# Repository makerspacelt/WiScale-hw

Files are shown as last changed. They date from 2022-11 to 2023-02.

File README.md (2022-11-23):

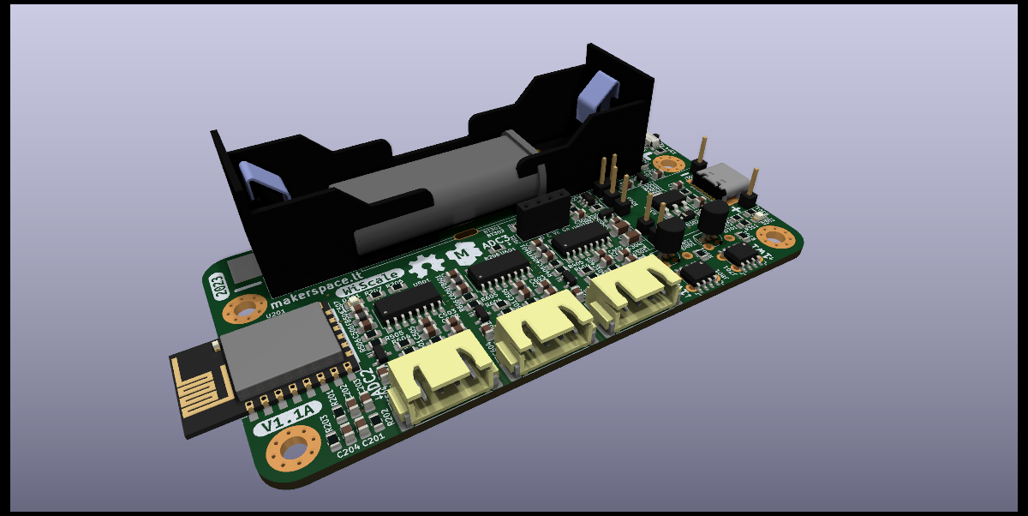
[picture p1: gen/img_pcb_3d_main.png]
PCB 3d main


This is ESP8266 (ESP-12F) and HX711 based weight monitoring device.

* Designed to be pretty small.
* Supports multiple load cells.
* Can be populated with 18650 battery
* Can be operated in ultra low power mode

Dev NOTE: before commit, run `./kibot.sh` to regenerate documentation, bom, gerbers and other assets.

* [schematics.pdf](gen/schematics.pdf)
* [pcb.pdf with dimensions](gen/pcb.pdf)
* [ibom.html](gen/bom_ibom.html)
* [gerbers.zip](gen/gerbers/gerbers.zip)

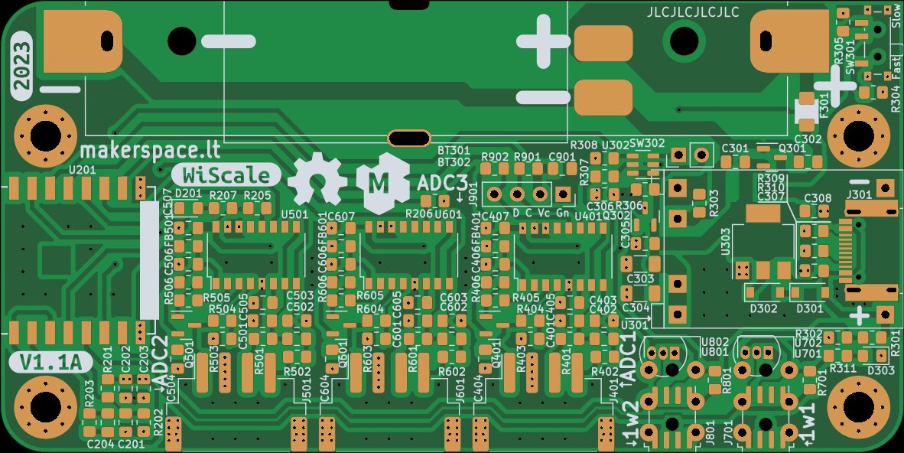
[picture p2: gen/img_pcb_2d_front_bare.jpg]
PCB 2d front bare

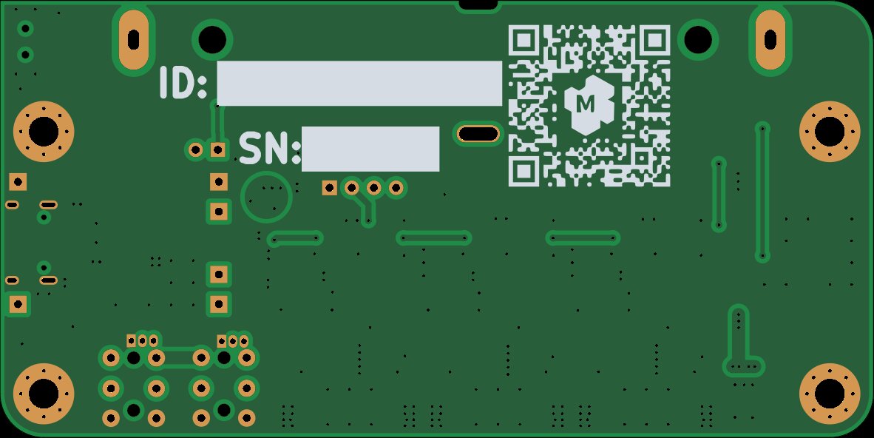
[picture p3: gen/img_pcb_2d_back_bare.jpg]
PCB 2d back bare


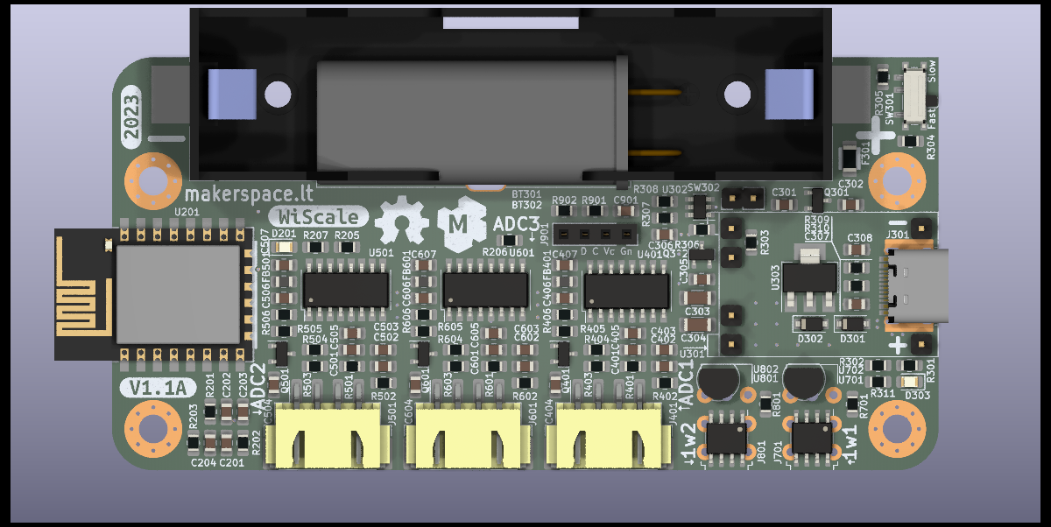
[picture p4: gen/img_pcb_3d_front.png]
PCB 3d front


## Normal operation

The circuit should be powered either via a USB connector on the LiPo charger
or battery.

## Assembly and hardware configuration notes

### LiPo charger

Chargers(U301) with protection can be used.

For use without onboard charger R303 must be shorted and U301,R301 and R302
can be omitted. 

### Low-power sleep

A timer is equipped with selectable(SW301) wake-up settings(R304 and R305).

For applications that do not require a low-power sleep, timer can be bypassed
by shorting out R306. Following components can be omitted in assembly:

* U302
* Q302
* SW301,SW302
* R304,R305,R307,R308

### ADC configuration

To reduce noise on measurements capacitors(C401,C402,C403) on ADC input are
placed. As a side effect, they slow down reading settling time after weight
change. Removing these capacitors will give a fast reading but increase spread
by about 3 times.

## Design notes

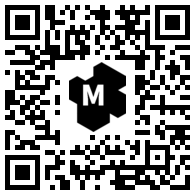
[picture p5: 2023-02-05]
gen/qr_link.png

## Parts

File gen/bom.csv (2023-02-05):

Row | Description | Part | References | Value | Footprint | Quantity Per PCB | Status | Datasheet | LCSC Part Number | MPN
1 | Single-cell battery | Battery_Cell | BT301 | 18650 | BAT_BH-18650-PC | 1 |  | https://datasheet.lcsc.com/lcsc/2204021730_MYOUNG-BH-18650-B1BA002_C2988620.pdf | C2988620 | BH-18650-B1BA002
2 | Single-cell battery | Battery_Cell | BT302 | 801437 | BAT_IP801437D3R2 | 1 |  | ~
3 | Unpolarized capacitor | C | C201,C202,C204,C305,C306,C401,C403,C405,C501,C503,C505,C601,C603,C605,C901 | 100n | C_0805_2012Metric_Pad1.18x1.45mm_HandSolder | 15 |  | ~
4 | Unpolarized capacitor | C | C402,C406,C502,C506,C602,C606 | 1u | C_0805_2012Metric_Pad1.18x1.45mm_HandSolder | 6 |  | ~
5 | Unpolarized capacitor | C | C203,C301,C302,C307,C308,C404,C407,C504,C507,C604,C607 | 10u | C_0805_2012Metric_Pad1.18x1.45mm_HandSolder | 11 |  | ~
6 | Unpolarized capacitor | C | C303,C304 | 100u | C_1206_3216Metric_Pad1.33x1.80mm_HandSolder | 2 |  | https://datasheet.lcsc.com/lcsc/1811061115_Murata-Electronics-GRM31CR61A107ME05L_C312983.pdf | C312983 | GRM31CR61A107ME05L
7 |  | 1N4148W | D301,D302 | 1N4148WL | D_SOD-123 | 2 |  | https://www.vishay.com/docs/85748/1n4148w.pdf | C2908120
8 | Light emitting diode | LED | D201 | BLUE | LED_0805_2012Metric_Pad1.15x1.40mm_HandSolder | 1 |  | https://datasheet.lcsc.com/lcsc/2211030000_XINGLIGHT-XL-2012UBC_C965817.pdf | C965817 | XL-2012UBC
9 | Light emitting diode | LED | D303 | GREEN | LED_0805_2012Metric_Pad1.15x1.40mm_HandSolder | 1 |  | https://datasheet.lcsc.com/lcsc/2211030000_XINGLIGHT-XL-2012UBC_C965817.pdf | C965817 | XL-2012UBC
10 | Resettable fuse, polymeric positive temperature coefficient | Polyfuse | F301 | PTC 1A | Fuse_1206_3216Metric_Pad1.42x1.75mm_HandSolder | 1 |  | https://datasheet.lcsc.com/lcsc/2105241640_Jinrui-Electronic-Materials-Co--JK-nSMD100-16V_C2830246.pdf | C2830246 | JK-nSMD100/16V
11 | Ferrite bead | FerriteBead | FB401,FB501,FB601 | bead | L_0805_2012Metric_Pad1.15x1.40mm_HandSolder | 3 |  | ~
12 | Audio Jack, 3 Poles (Stereo / TRS) | AudioJack3 | J701,J801 | DS18B20 | Jack_3.5mm_Horizontal | 2 |  | ~
13 | Generic connectable mounting pin connector, single row, 01x03, script generated (kicad-library-utils/schlib/autogen/connector/) | Conn_01x03_MountingPin | J1001,J1002,J1003,J1004 | TL | JST_XH_S3B-XH-A-1_1x03_P2.50mm_Horizontal | 4 |  | ~
14 | USB 2.0-only Type-C Receptacle connector | USB_C_Receptacle_USB2.0 | J301 | USB_POWER_IN | USB_C_Receptacle_HRO_TYPE-C-31-M-12 | 1 |  | https://datasheet.lcsc.com/lcsc/2205251630_Korean-Hroparts-Elec-TYPE-C-31-M-12_C165948.pdf | C165948
15 | Generic connectable mounting pin connector, single row, 01x04, script generated (kicad-library-utils/schlib/autogen/connector/) | Conn_01x04_MountingPin | J401,J501,J601,J1005 | cell | JST_XH_S4B-XH-SM4-TB_1x04-1MP_P2.50mm_Horizontal | 4 |  | https://datasheet.lcsc.com/lcsc/1810291321_JST-Sales-America-S4B-XH-SM4-TB-LF-SN_C161861.pdf | C2905026 | S4B-XH-SM4-TB(LF)(SN)
16 | Generic connectable mounting pin connector, single row, 01x04, script generated (kicad-library-utils/schlib/autogen/connector/) | Conn_01x04_MountingPin | J901 | i2c | PinSocket_1x04_P2.54mm_Vertical | 1 |  | ~
17 | -4.0A Id, -30V Vds, P-Channel MOSFET, SOT-23 | AO3401A | Q301,Q302,Q401,Q501,Q601 | AO3401A | SOT-23 | 5 |  | http://www.aosmd.com/pdfs/datasheet/AO3401A.pdf | C347476 | AO3401A
18 | Resistor | R | R207,R307,R401,R402,R405,R501,R502,R505,R601,R602,R605 | 100 | R_0805_2012Metric_Pad1.20x1.40mm_HandSolder | 11 |  | ~
19 | Resistor | R | R308,R309,R310,R311,R701,R801,R901,R902 | 4k7 | R_0805_2012Metric_Pad1.20x1.40mm_HandSolder | 8 |  | ~
20 | Resistor | R | R203,R205,R206 | 10k | R_0805_2012Metric_Pad1.20x1.40mm_HandSolder | 3 |  | ~
21 | Resistor | R | R304 | 15k | R_0805_2012Metric_Pad1.20x1.40mm_HandSolder | 1 |  | ~
22 | Resistor | R | R202,R301 | 47k | R_0805_2012Metric_Pad1.20x1.40mm_HandSolder | 2 |  | ~
23 | Resistor | R | R201,R302,R305,R403,R406,R503,R506,R603,R606 | 180k | R_0805_2012Metric_Pad1.20x1.40mm_HandSolder | 9 |  | ~
24 | Resistor | R | R404,R504,R604 | 200k | R_0805_2012Metric_Pad1.20x1.40mm_HandSolder | 3 |  | ~
25 | Switch, single pole double throw | SW_SPDT | SW301 | SW_SPDT | SW_SPDT_PCM12 | 1 |  | https://datasheet.lcsc.com/lcsc/1912111437_SHOU-HAN-MSK12C02_C431540.pdf | C431540 | MSK12C02
26 | Push button switch, generic, two pins | SW_Push | SW302 | btn | PinHeader_1x02_P2.54mm_Vertical | 1 |  | ~
27 | 1A Low Dropout regulator, positive, 3.3V fixed output, SOT-223 | AMS1117-3.3 | U303 | AMS1117-3.3 | SOT-223-3_TabPin2 | 1 |  | http://www.advanced-monolithic.com/pdf/ds1117.pdf
28 |  | BMS_USB_LiPo_Charger | U301 | BMS_USB_LiPo_Charger | module_bms_usb_lipo_charger | 1
29 | Programmable Resolution 1-Wire Digital Thermometer TO-92 | DS18B20 | U702,U802 | DS18B20 | TO-92_Inline | 2 |  | http://datasheets.maximintegrated.com/en/ds/DS18B20.pdf
30 | Programmable Resolution 1-Wire Digital Thermometer SOIC-8 | DS18B20Z | U701,U801 | DS18B20Z | SOIC-8_3.9x4.9mm_P1.27mm | 2 |  | http://datasheets.maximintegrated.com/en/ds/DS18B20.pdf
31 | 802.11 b/g/n Wi-Fi Module | ESP-07 | U201 | ESP-7(S) or ESP-12* | ESP-12S | 1 |  | https://www.espressif.com/sites/default/files/documentation/0a-esp8266ex_datasheet_en.pdf | C89297 | ESP-12E
32 | 2-channel, differential, 24-bit ADC, SOP-16 package | HX711 | U401,U501,U601 | HX711 | SOP-16_4.4x10.4mm_P1.27mm | 3 |  | https://cdn.sparkfun.com/datasheets/Sensors/ForceFlex/hx711_english.pdf | C43656 | HX711
33 | Timer, Nano Power, Active-Low, 35 nA, 100 ms to 7200 s, VDD 1.8V to 5.5V, Iout max 1mA, SOT-23-6 | TPL5110 | U302 | TPL5110 | SOT-23-6 | 1 |  | http://www.ti.com/lit/ds/symlink/tpl5110.pdf | C125830 | TPL5110

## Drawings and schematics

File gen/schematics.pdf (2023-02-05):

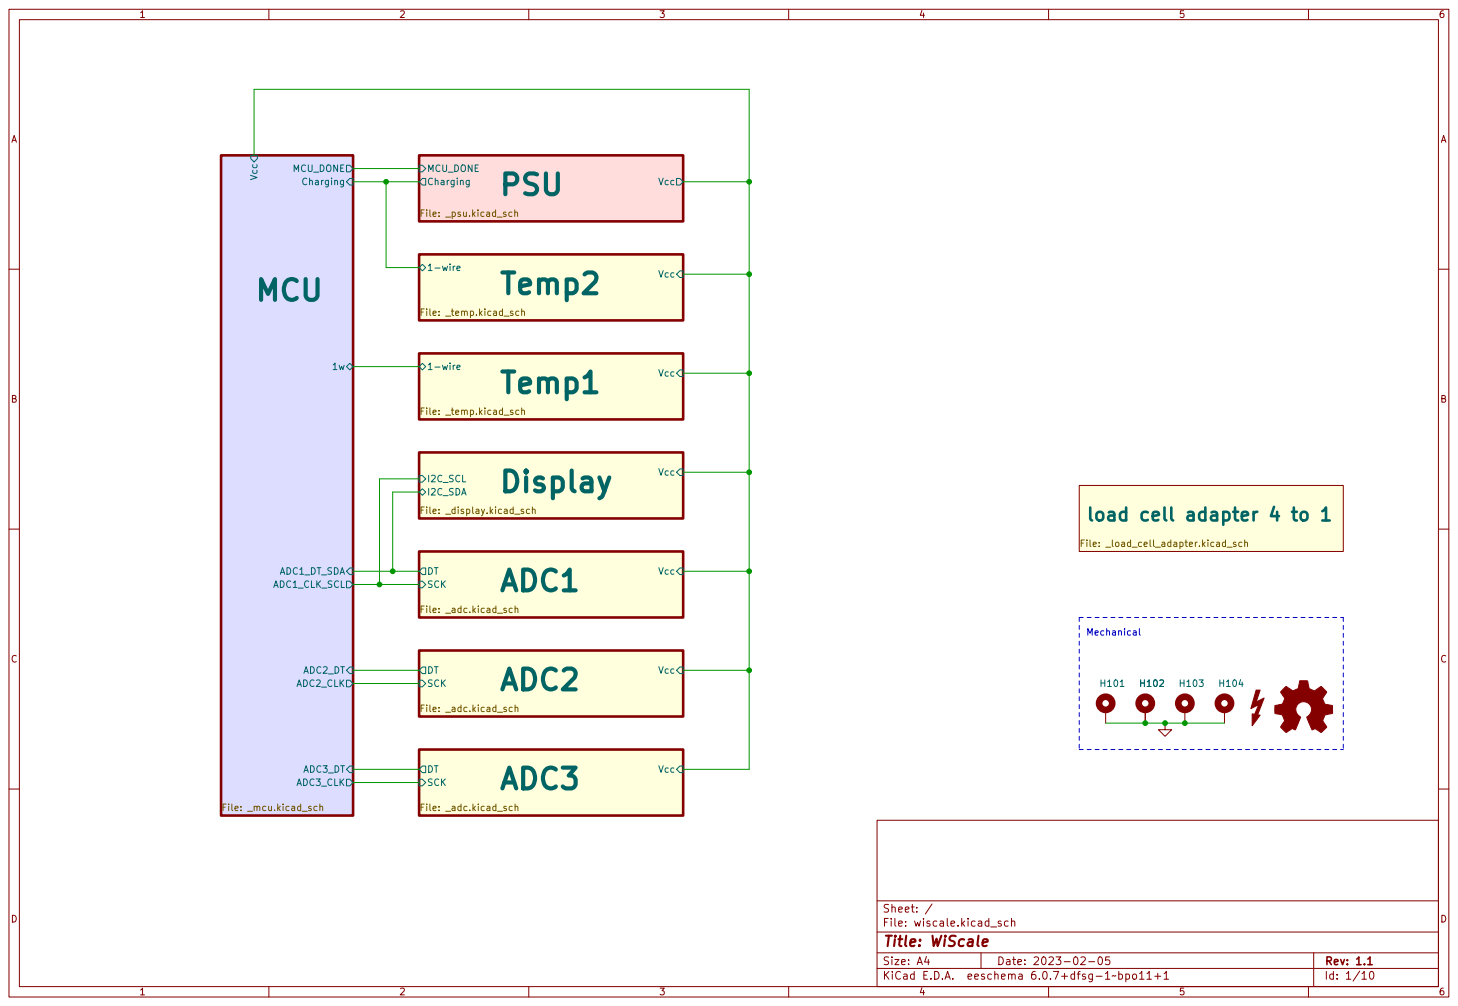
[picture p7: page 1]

load cell adapter 4 to 1

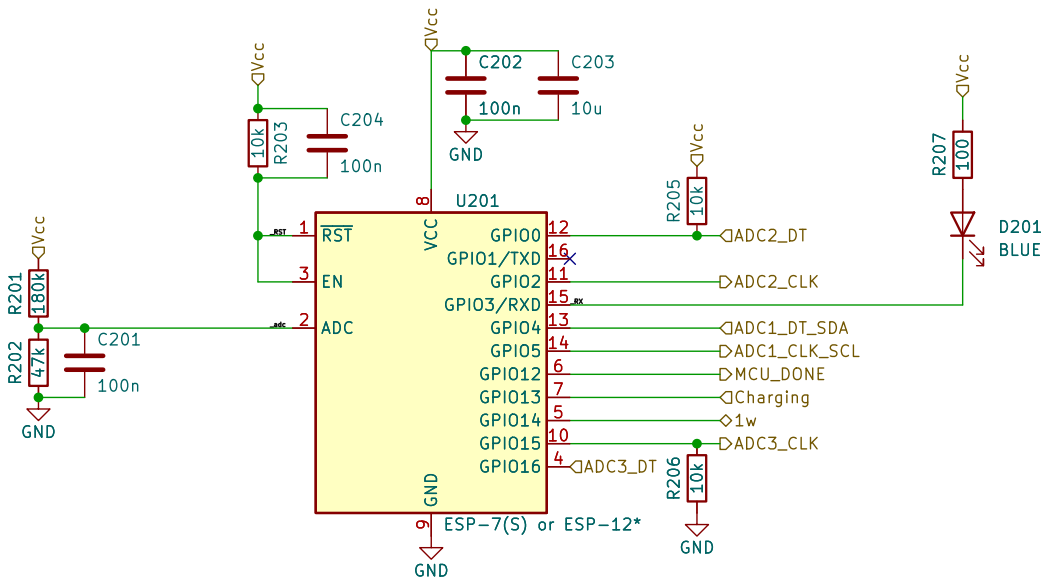
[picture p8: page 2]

9 U201 ESP-7(S) or ESP-12* R207 100 D201 BLUE C203

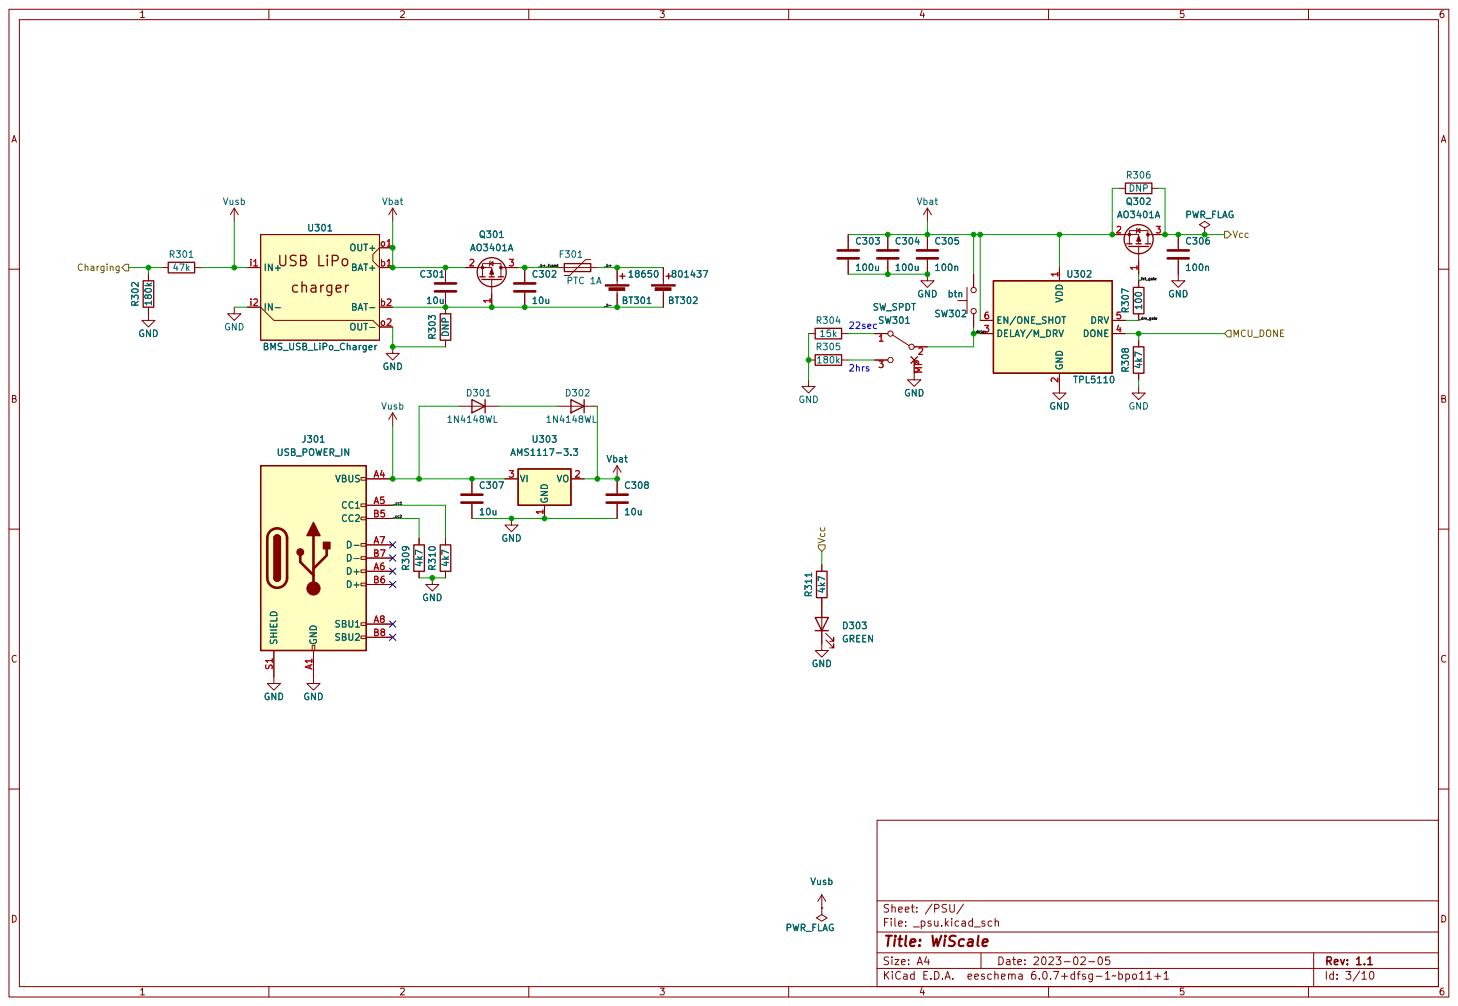
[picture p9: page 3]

2 DELAY/M_DRV 3 DONE 4 DRV 5 EN/ONE_SHOT 6 U302 TPL5110 GND

2 DELAY/M_DRV 3 DONE 4 DRV 5 EN/ONE_SHOT 6 GND GND

1 VO 2 VI 3 U303 AMS1117-3.3 GND A1 VBUS A4 CC1 A5 D+ A6 D- A7 SBU1 A8 CC2 B5 D+ B6 D- B7 SBU2 B8 SHIELD S1

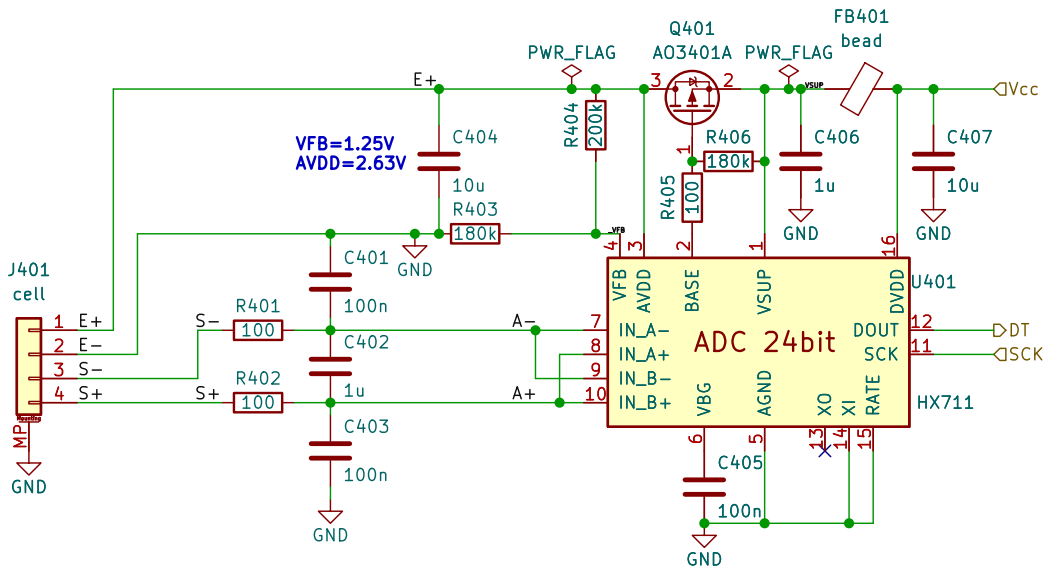
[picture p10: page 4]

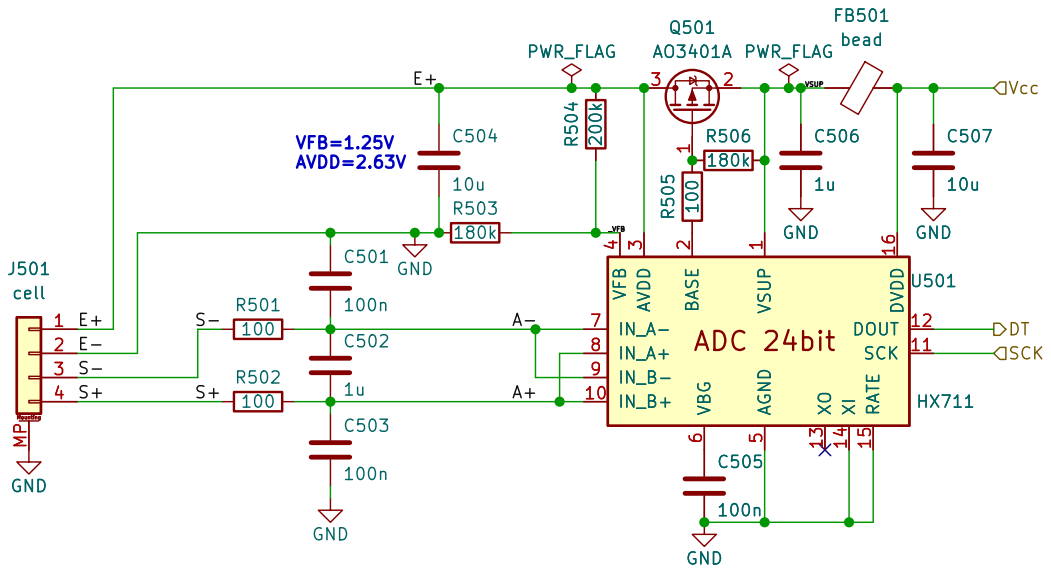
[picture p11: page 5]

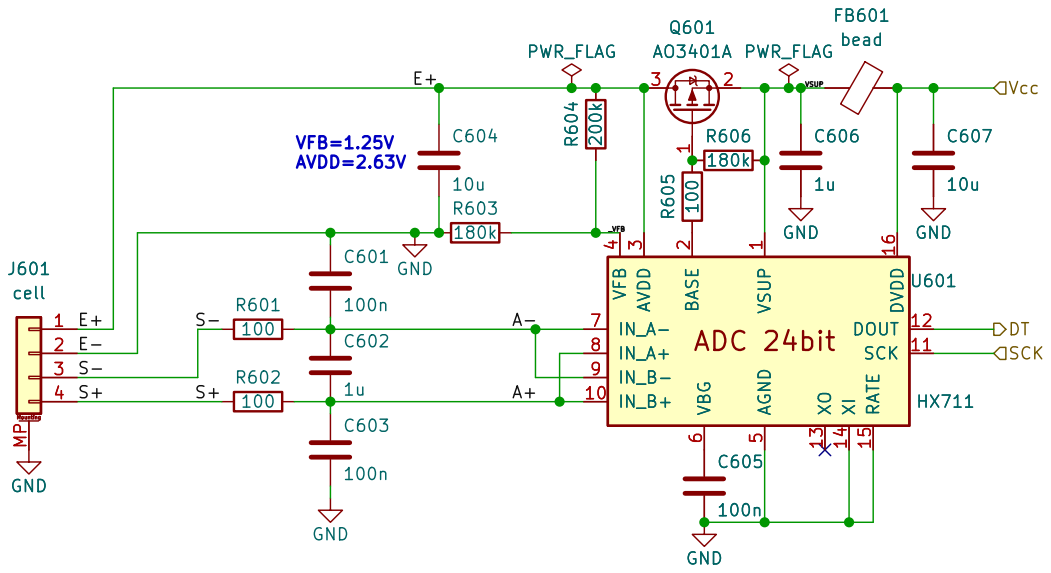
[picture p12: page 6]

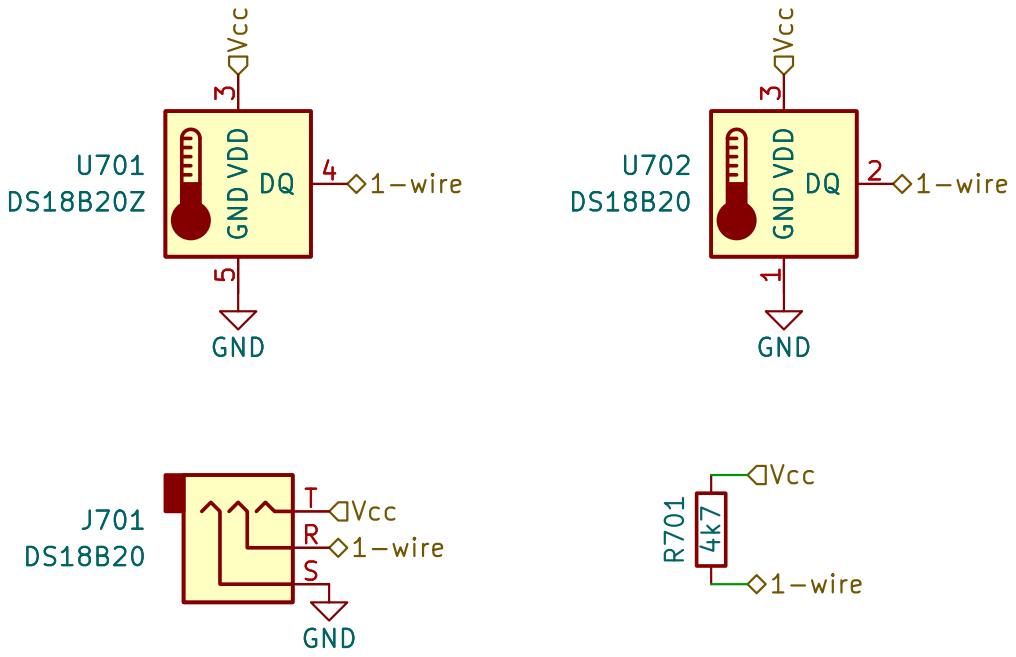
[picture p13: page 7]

5 U701 DS18B20Z GND R701 4k7 GND Vcc 1-wire Vcc Vcc Vcc 1-wire

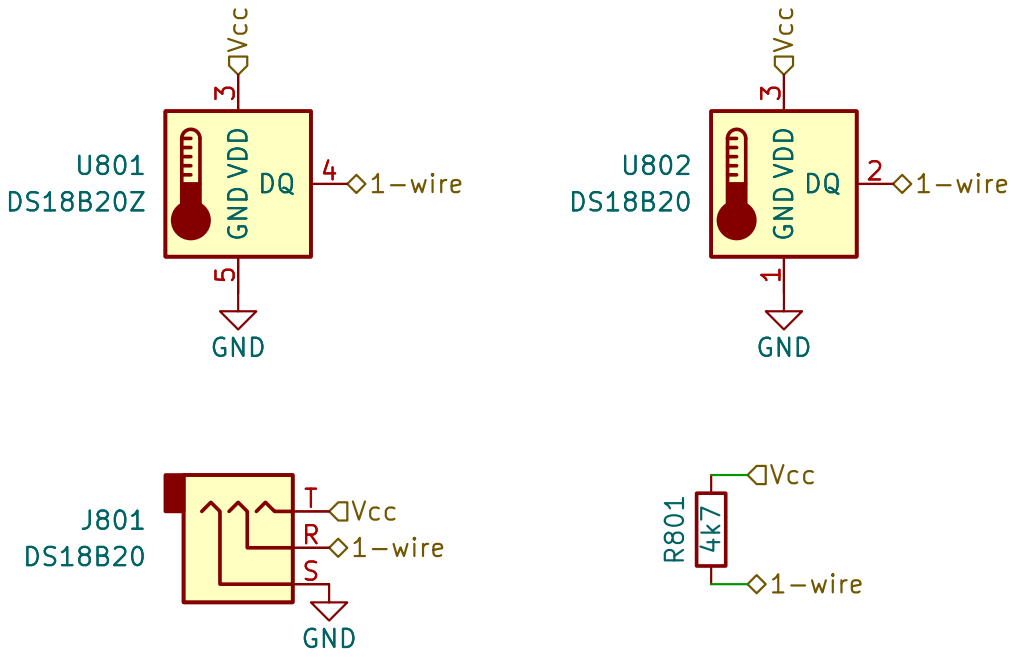
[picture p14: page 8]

5 U801 DS18B20Z GND R801 4k7 GND Vcc 1-wire Vcc Vcc Vcc 1-wire

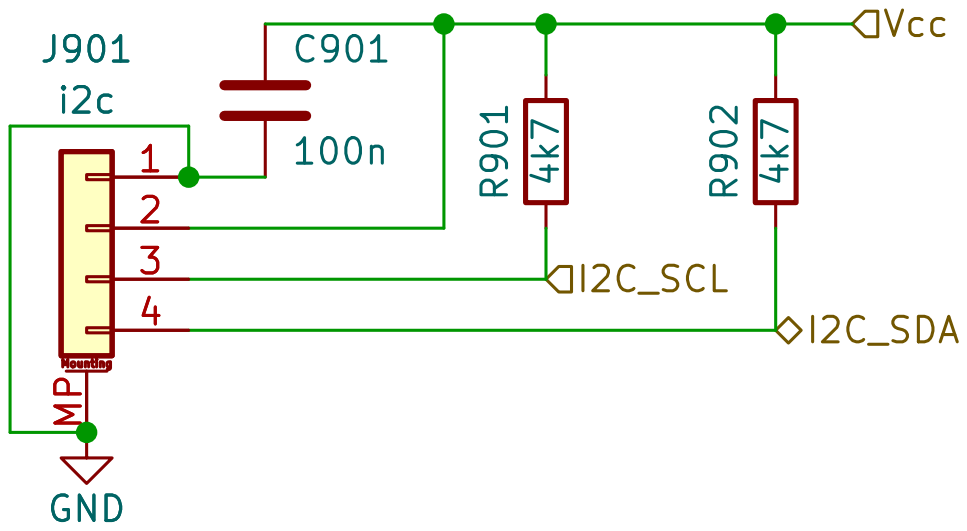
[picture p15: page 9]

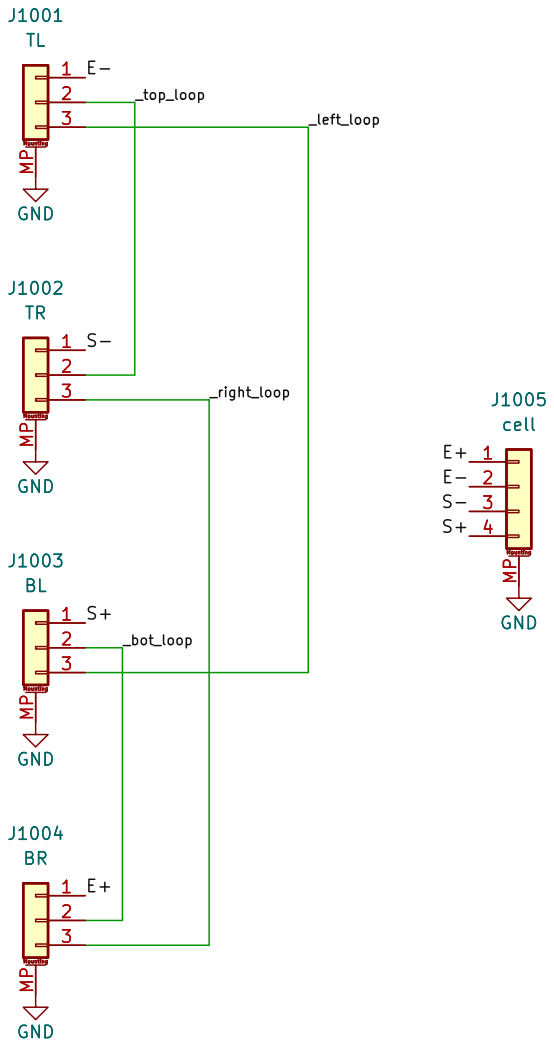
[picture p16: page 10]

J1003 BL GND GND GND

Sheet: /load cell adapter 4 to 1/ GND

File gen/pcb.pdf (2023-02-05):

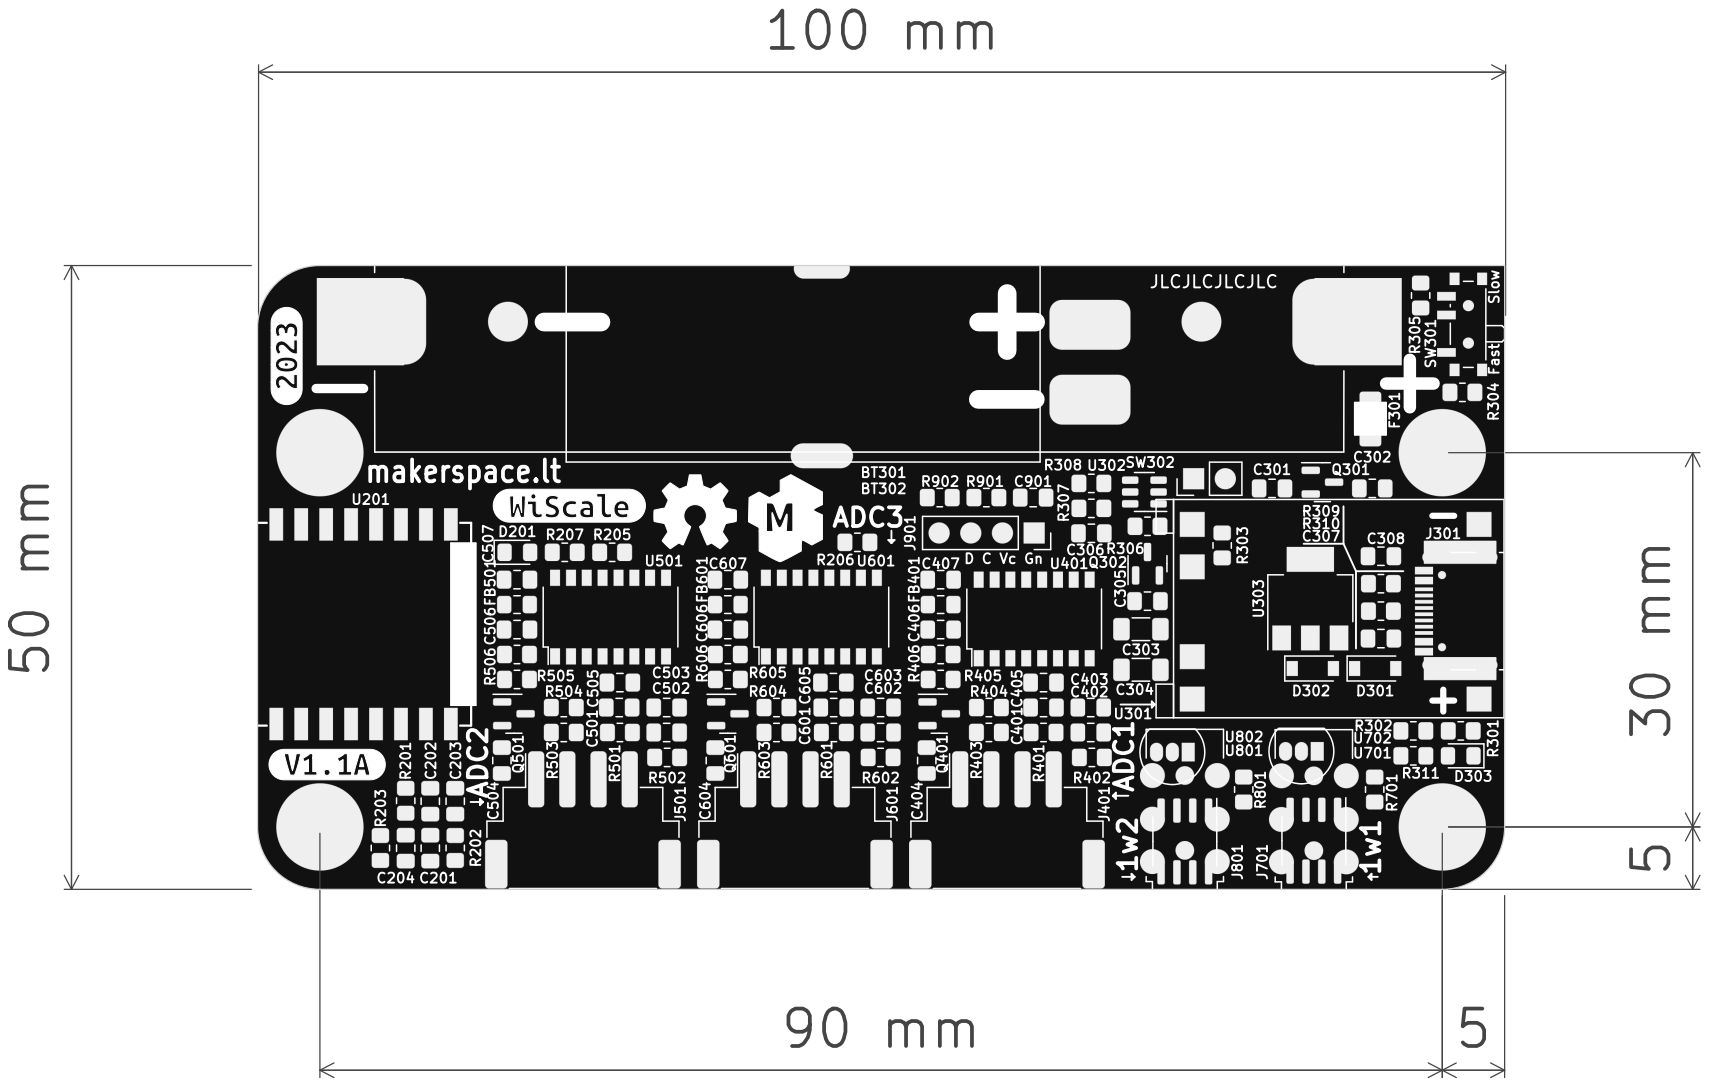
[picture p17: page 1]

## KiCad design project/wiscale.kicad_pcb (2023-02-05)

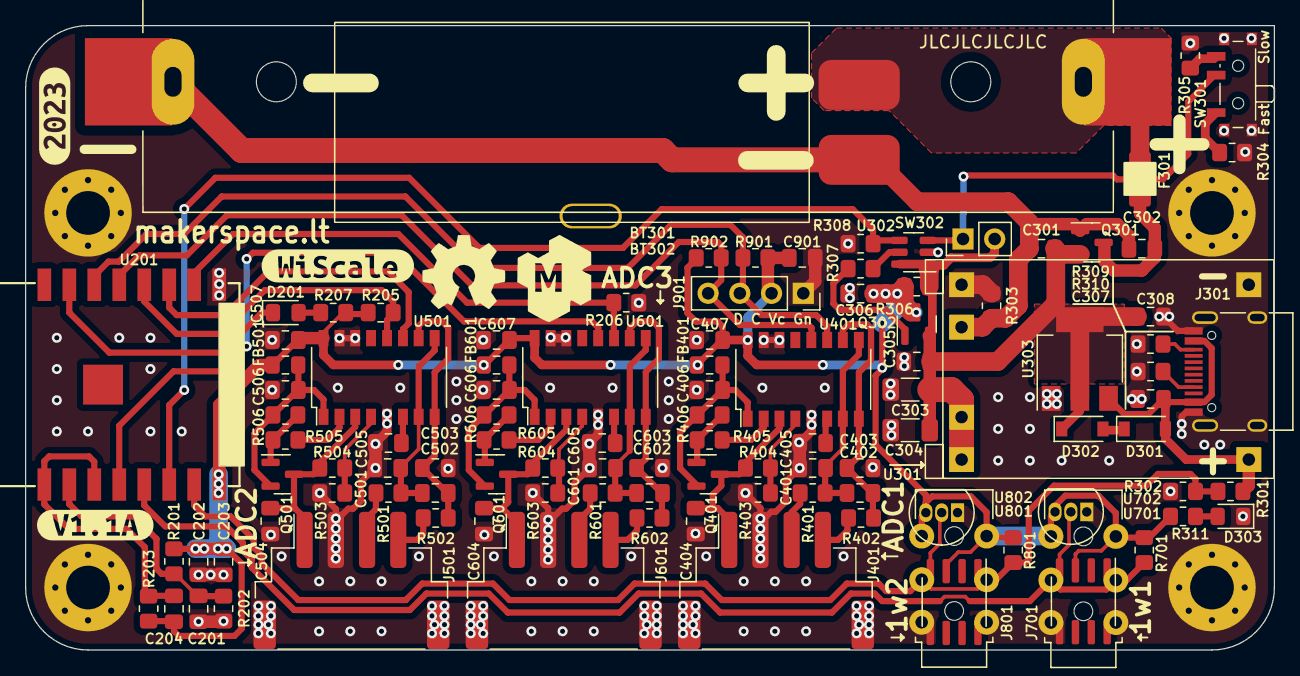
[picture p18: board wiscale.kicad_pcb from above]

Board: 2 copper layers, 100.0 x 50.0 mm, 117 parts (0 on the bottom side), 59 nets.

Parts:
BT301: 18650; BAT_BH-18650-PC
BT302: 801437; BAT_IP801437D3R2
C201, C202, C204, C305, C306, C401, C403, C405, C501, C503, C505, C601, C603, C605, C901: 100n; C_0805_2012Metric_Pad1.18x1.45mm_HandSolder
C203, C301, C302, C307, C308, C404, C407, C504, C507, C604, C607: 10u; C_0805_2012Metric_Pad1.18x1.45mm_HandSolder
C303, C304: 100u; C_1206_3216Metric_Pad1.33x1.80mm_HandSolder
C402, C406, C502, C506, C602, C606: 1u; C_0805_2012Metric_Pad1.18x1.45mm_HandSolder
D201: BLUE; LED_0805_2012Metric_Pad1.15x1.40mm_HandSolder
D301, D302: 1N4148WL; D_SOD-123
D303: GREEN; LED_0805_2012Metric_Pad1.15x1.40mm_HandSolder
F301: PTC 1A; Fuse_1206_3216Metric_Pad1.42x1.75mm_HandSolder
FB401, FB501, FB601: bead; L_0805_2012Metric_Pad1.15x1.40mm_HandSolder
H101, H102, H103, H104: MountingHole_Pad; MountingHole_3.5mm_Pad_Via
J301: USB_POWER_IN; USB_C_Receptacle_HRO_TYPE-C-31-M-12
J401, J501, J601: cell; JST_XH_S4B-XH-SM4-TB_1x04-1MP_P2.50mm_Horizontal
J701, J801: DS18B20; Jack_3.5mm_Horizontal
J901: i2c; PinSocket_1x04_P2.54mm_Vertical
LOGO101: logo_kms_small; logo_kms_small_silkscreen
LOGO102: Logo_Open_Hardware_Small; OSHW-Symbol_6.7x6mm_SilkScreen
Q301, Q302, Q401, Q501, Q601: AO3401A; SOT-23
R201, R302, R305, R403, R406, R503, R506, R603, R606: 180k; R_0805_2012Metric_Pad1.20x1.40mm_HandSolder
R202, R301: 47k; R_0805_2012Metric_Pad1.20x1.40mm_HandSolder
R203, R205, R206: 10k; R_0805_2012Metric_Pad1.20x1.40mm_HandSolder
R207, R307, R401, R402, R405, R501, R502, R505, R601, R602, R605: 100; R_0805_2012Metric_Pad1.20x1.40mm_HandSolder
R303, R306: DNP; R_0805_2012Metric_Pad1.20x1.40mm_HandSolder
R304: 15k; R_0805_2012Metric_Pad1.20x1.40mm_HandSolder
R308, R309, R310, R311, R701, R801, R901, R902: 4k7; R_0805_2012Metric_Pad1.20x1.40mm_HandSolder
R404, R504, R604: 200k; R_0805_2012Metric_Pad1.20x1.40mm_HandSolder
SW301: SW_SPDT; SW_SPDT_PCM12
SW302: btn; PinHeader_1x02_P2.54mm_Vertical
U201: ESP-7(S) or ESP-12*; ESP-12S
U301: BMS_USB_LiPo_Charger; module_bms_usb_lipo_charger
U302: TPL5110; SOT-23-6
U303: AMS1117-3.3; SOT-223-3_TabPin2
U401, U501, U601: HX711; SOP-16_4.4x10.4mm_P1.27mm
U701, U801: DS18B20Z; SOIC-8_3.9x4.9mm_P1.27mm
U702, U802: DS18B20; TO-92_Inline
kibuzzard-63DFF7BC: G***; kibuzzard-63DFF7BC
kibuzzard-63DFF7CA: G***; kibuzzard-63DFF7CA
kibuzzard-637D024E: G***; kibuzzard-637D024E

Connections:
/ADC1/A+: C402.2, C403.2, R402.1, U401.8 (IN_A+), U401.10 (IN_B+)
/ADC1/A-: C401.1, C402.1, R401.1, U401.7 (IN_A-), U401.9 (IN_B-)
/ADC1/DT: J901.4, R902.1, U201.13 (GPIO4), U401.12 (DOUT)
/ADC1/E+: C404.2, J401.1, Q401.3 (D), R404.1, U401.3 (AVDD)
/ADC1/S+: J401.4, R402.2
/ADC1/S-: J401.3, R401.2
/ADC1/SCK: J901.3, R901.1, U201.14 (GPIO5), U401.11 (SCK)
/ADC1/Vcc: C202.2, C203.2, C204.2, C306.2, C407.2, C507.2, C607.2, C901.2, FB401.1, FB501.1, FB601.1, J701.T, J801.T, J901.2, Q302.3 (D), R201.2, R203.1, R205.2, R207.2, R306.2, R311.2, R701.2, R801.2, R901.2, R902.2, U201.8 (VCC), U401.16 (DVDD), U501.16 (DVDD), U601.16 (DVDD), U701.3 (VDD), U702.3 (VDD), U801.3 (VDD), U802.3 (VDD)
/ADC1/_VFB: R403.1, R404.2, U401.4 (VFB)
/ADC1/_VSUP: C406.2, FB401.2, Q401.2 (S), R406.2, U401.1 (VSUP)
/ADC2/A+: C502.2, C503.2, R502.1, U501.8 (IN_A+), U501.10 (IN_B+)
/ADC2/A-: C501.1, C502.1, R501.1, U501.7 (IN_A-), U501.9 (IN_B-)
/ADC2/DT: R205.1, U201.12 (GPIO0), U501.12 (DOUT)
/ADC2/E+: C504.2, J501.1, Q501.3 (D), R504.1, U501.3 (AVDD)
/ADC2/S+: J501.4, R502.2
/ADC2/S-: J501.3, R501.2
/ADC2/SCK: U201.11 (GPIO2), U501.11 (SCK)
/ADC2/_VFB: R503.1, R504.2, U501.4 (VFB)
/ADC2/_VSUP: C506.2, FB501.2, Q501.2 (S), R506.2, U501.1 (VSUP)
/ADC3/A+: C602.2, C603.2, R602.1, U601.8 (IN_A+), U601.10 (IN_B+)
/ADC3/A-: C601.1, C602.1, R601.1, U601.7 (IN_A-), U601.9 (IN_B-)
/ADC3/DT: U201.4 (GPIO16), U601.12 (DOUT)
/ADC3/E+: C604.2, J601.1, Q601.3 (D), R604.1, U601.3 (AVDD)
/ADC3/S+: J601.4, R602.2
/ADC3/S-: J601.3, R601.2
/ADC3/SCK: R206.2, U201.10 (GPIO15), U601.11 (SCK)
/ADC3/_VFB: R603.1, R604.2, U601.4 (VFB)
/ADC3/_VSUP: C606.2, FB601.2, Q601.2 (S), R606.2, U601.1 (VSUP)
/MCU/1w: J701.R, R701.1, U201.5 (GPIO14), U701.4 (DQ), U702.2 (DQ)
/MCU/Charging: J801.R, R301.1, R302.2, R801.1, U201.7 (GPIO13), U801.4 (DQ), U802.2 (DQ)
/MCU/MCU_DONE: R308.2, U201.6 (GPIO12), U302.4 (DONE)
/MCU/_RST: C204.1, R203.2, U201.1 (~RST), U201.3 (EN)
/MCU/_RX: D201.1 (K), U201.15 (GPIO3/RXD)
/MCU/_adc: C201.2, R201.1, R202.2, U201.2 (ADC)
/PSU/_b+: BT301.1 (+), BT302.1 (+), F301.2
/PSU/_b+_fused: C302.2, F301.1, Q301.3 (D)
/PSU/_b-: BT301.2 (-), BT302.2 (-), C301.1, C302.1, Q301.1 (G), R303.2, U301.b2 (BAT-)
/PSU/_cc1: J301.A5 (CC1), R310.2
/PSU/_cc2: J301.B5 (CC2), R309.2
/PSU/_delay: SW301.2 (B), SW302.1, U302.3 (DELAY/M_DRV)
/PSU/_drv_gate: R307.1, U302.5 (DRV)
/PSU/_fet_gate: Q302.1 (G), R307.2
GND: C201.1, C202.1, C203.1, C303.1, C304.1, C305.1, C306.1, C307.1, C308.1, C401.2, C403.1, C404.1, C405.1, C406.1, C407.1, C501.2, C503.1, C504.1, C505.1, C506.1, C507.1, C601.2, C603.1, C604.1, C605.1, C606.1, C607.1, C901.1, D303.1 (K), H101.1, H102.1, H103.1, H104.1, J301.A1 (GND), J301.A12 (GND), J301.B1 (GND), J301.B12 (GND), J301.S1 (SHIELD), J401.2, J401.MP (MountPin), J501.2, J501.MP (MountPin), J601.2, J601.MP (MountPin), J701.S, J801.S, J901.1, R202.1, R206.1, R302.1, R303.1, R304.1, R305.1, R308.1, R309.1, R310.1, R403.2, R503.2, R603.2, SW301.MP, U201.9 (GND), U301.i2 (IN-), U301.o2 (OUT-), U302.2 (GND), U303.1 (GND), U401.5 (AGND), U401.14 (XI), U401.15 (RATE), U501.5 (AGND), U501.14 (XI), U501.15 (RATE), U601.5 (AGND), U601.14 (XI), U601.15 (RATE), U701.5 (GND), U702.1 (GND), U801.5 (GND), U802.1 (GND)
unnamed: C405.2, U401.6 (VBG)
unnamed: C505.2, U501.6 (VBG)
unnamed: C605.2, U601.6 (VBG)
unnamed: D201.2 (A), R207.1
unnamed: D301.1 (K), D302.2 (A)
unnamed: D303.2 (A), R311.1
unnamed: Q401.1 (G), R405.1, R406.1
unnamed: Q501.1 (G), R505.1, R506.1
unnamed: Q601.1 (G), R605.1, R606.1
unnamed: R304.2, SW301.1 (A)
unnamed: R305.2, SW301.3 (C)
unnamed: R405.2, U401.2 (BASE)
unnamed: R505.2, U501.2 (BASE)
unnamed: R605.2, U601.2 (BASE)
Vbat: C301.2, C303.2, C304.2, C305.2, C308.2, D302.1 (K), Q301.2 (S), Q302.2 (S), R306.1, SW302.2, U301.b1 (BAT+), U301.o1 (OUT+), U302.1 (VDD), U302.6 (EN/ONE_SHOT), U303.2 (VO)
Vusb: C307.2, D301.2 (A), J301.A4 (VBUS), J301.A9 (VBUS), J301.B4 (VBUS), J301.B9 (VBUS), R301.2, U301.i1 (IN+), U303.3 (VI)

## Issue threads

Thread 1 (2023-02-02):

Fails to boot into normal mode for operation

dariuskt, 2023-02-02:
on normal startup, due to high-value boot mode select resistors and the absence of capacitance on RST pin, starts up MCU before boot mode values had settled resulting in incorrect boot mode and failure to boot.

* lower values of boot mode select resistors to 10k (to select boot mode faster)
* add 100nF cap on RST pin (to slow down reset, and give more time to boot mode selection)

Closed 2023-02-05.

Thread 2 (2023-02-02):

Charging detection is incorrect

dariuskt, 2023-02-02:
R301 and R302 should form a resistive divider that divides USB input voltage for reading via esp GPIO. That means the pull-down resistor should be on the esp side

Closed 2023-02-05.

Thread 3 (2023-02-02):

Can't detect external power while using LDO path

dariuskt, 2023-02-02:
connecting `_usb_vbus` and `_vusb` together might solve this issue

Closed 2023-02-05.

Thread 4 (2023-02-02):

Poor mechanical attachment of USB-C connector

dariuskt, 2023-02-02:
expose more copper around the USB-C connector for easier soldering and better mechanical adhesion

Closed 2023-02-05.

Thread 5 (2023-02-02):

Fluctuating battery voltage readings

dariuskt, 2023-02-02:
add 100nF cap to esp ADC pin to stabilize the battery voltage

Closed 2023-02-05.

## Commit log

2022-11-22 adding initial project
    [_adc.kicad_sch, _display.kicad_sch, _mcu.kicad_sch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]
2022-11-22 adding generated files
    [wiscale--NPTH_map.gbr, wiscale--PTH_map.gbr, wiscale-B_Cu.gbr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]
2022-11-23 extracting load cell adapter to its own page
    [_adc.kicad_sch, _load_cell_adapter.kicad_sch, _mcu.kicad_sch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]
2022-11-24 various small improvements
    [_load_cell_adapter.kicad_sch, _mcu.kicad_sch, _psu.kicad_sch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]
2022-11-24 fixing bom, datasheets and adding link to repo
    [_adc.kicad_sch, _display.kicad_sch, _load_cell_adapter.kicad_sch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]
2022-11-25 adding usb port with ldo and diode options
    [_psu.kicad_sch, bom.csv, bom_lcsc.csv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]
2022-11-26 removing metalization from the hole on the edge for manufacturing
    [wiscale--NPTH_map.gbr, wiscale--PTH_map.gbr, wiscale-B_Cu.gbr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]
2023-02-05 fixing mode select resistors values, related to #1
    [_mcu.kicad_sch, bom.csv, wiscale.kicad_pcb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]
2023-02-05 consolidating RST with EN and adding a capacitor for stability. fixes #1
    [_mcu.kicad_sch, bom.csv, wiscale.kicad_pcb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]
2023-02-05 fixing charging detection divider, fixes #2
    [_adc.kicad_sch, _display.kicad_sch, _load_cell_adapter.kicad_sch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]
2023-02-05 connected LDO USB power with charger USB power, fixes #3
    [_psu.kicad_sch, wiscale.kicad_pcb, wiscale.kicad_sch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]
2023-02-05 improving USB-C connector solderability. fixes #4
    [wiscale.kicad_pcb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]
2023-02-05 adding more labels on silkscreen and bumping up version to 1.1
    [_adc.kicad_sch, _display.kicad_sch, _load_cell_adapter.kicad_sch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]
